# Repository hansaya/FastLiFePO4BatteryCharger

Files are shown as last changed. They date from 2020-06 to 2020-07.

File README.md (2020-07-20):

Fast battery charger designed to work with LifePo4 batteries using bq24630.

Features
* Selectable battery configuration. Up to 7S.
* Charge management based on temperature. Covers cold and warm conditions.
* Automatic system output selection based on power input conditions.
* No back feeding the input.
* High charging current up to 10A.
* Adjustable max input current limit.
* Adjustable max output current.
* Adjustable charge termination current.
* External enable pin can be used to turn on the charger. This is useful when you want to use the car ignition switch to trigger the charging.

More info at https://www.ti.com/lit/ds/symlink/bq24630.pdf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

# Disclaimer

**I’m not responsible for any life or property damage. Do your own research and use my design at your own risk. Lithium batteries can be dangerous.**

# My use case

I currently own an dash cam that can record time lapses while car is parked. This is a great feature and find it to be useful. However this requires the camera to be connected to constant power source. Plugging a camera into car battery permanently will get you a empty battery eventually. Specially if you don’t start the car every day. My solution to this problem is to have an secondary battery pack that powers the camera. 

My requirements:
1) Fast charge the battery within 20min or so. ie within in my daily commute.
2) Battery pack needs to handle the high heat and subzero conditions safely.
3) Runs system like a UPS. No interruptions to the output.
4) High charge cycles so that system would last for a long time.

# Design consideration.
1)	Picked bq24630 ic by TI as the solution to this problem. Which covers all my asks.
2)	Picked LifePo4 battery pack for temperature and charge cycle resiliency. Plus less like to detonate inside the car.
3)	2-layes 1oz board to make PCB house manufacturing cost down.
4)	Went with 3S configuration to keep the battery voltage bellow the input voltage. Bq24630 only a buck converter so it needs some head room.
5)	Keep the battery management work out of this design for simplicity.

# Board files

You can use the zip file within cam/ folder to get the board made by a PCB house. Board can be made with 2-layer and 1oz copper. If you have the money for higher copper thickness go for it but not required. 

## Assembling the board

* Do SMT soldering for all parts except for connectors and the fuse holders. 
* Trim pots are not required but recommended if you want to tweak the current settings. If you do select the trim ports, **DO NOT INSTALL R4, R5, R16, R17, R18 and R19.** R4 and R5 is used to set the charging current, R17 and R17 for termination current and finally R18 and R19 is for adapter current limit. Default values set on schematic designed for 4A adapter current limit, 3A charging current limit and 0.3A termination current.
* NTC thermistor required to let the charger operate at full current. 1.9v at the NTC positive legs could trigger into normal operation mode for testing.
* Add solder to no mask section to increase the current capabilities. This is how I got away with 1oz copper.
* R13 and R14 can be used to set the output voltage. Use 1.8(1+R13/R14) to set the voltage. My schematic sets this at 10.8V (LifePo4 3S).
* C11 can be used to set the safety timer. Checkout the datasheet for more information.
* P-CH mosfets I picked are only designed for 20v so do not exceed 20v input voltage.
* LED outputs are not required but handy to have.
* EN solder jumper can be used to permanently turn on the input.
* TB1 cab be used to reroute the charge enable pin to the external connector. Use a sharp knife to cut the trace between default charge enable tab.
* Q7 is optional if the charger needs to be enabled by default. Use a jumper to bridge the mosfet pads.

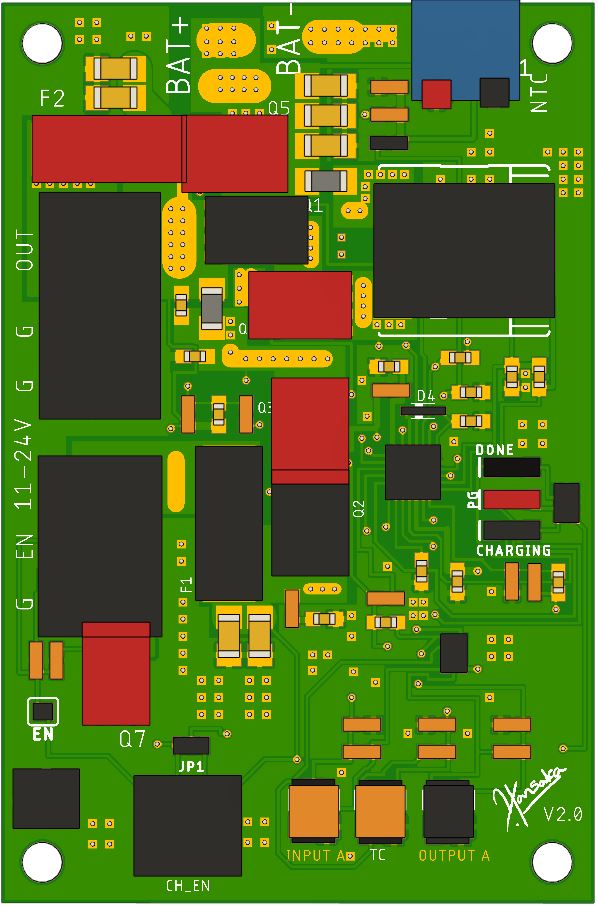
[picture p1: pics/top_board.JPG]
Top Board look

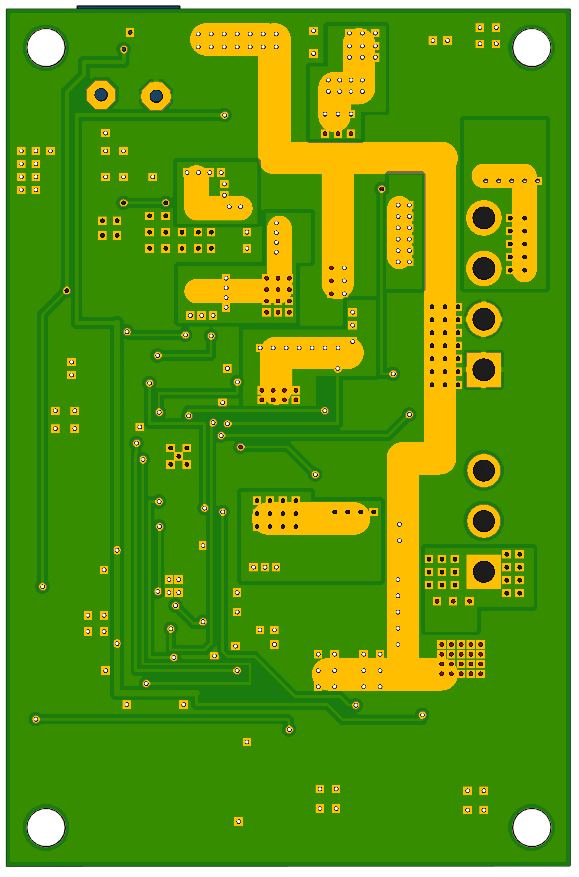
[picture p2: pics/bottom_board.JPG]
Bottom board look


# Other considerations

* Install an external battery protection system between the battery and the charger. 
* Even though charger can do 10A, inductor seems to get bit toasty at that level of current. I find 6A to be a happy medium.

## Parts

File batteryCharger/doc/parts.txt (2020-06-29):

bq24630 Standalone Synchronous Switched-Mode Lithium Phosphate Battery Charger
https://www.ti.com/lit/ds/symlink/bq24630.pdf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
https://www.digikey.com/product-detail/en/vishay-siliconix/SIR401DP-T1-GE3/SIR401DP-T1-GE3CT-ND/6595354

current sensing https://www.digikey.com/product-detail/en/panasonic-electronic-components/ERJ-8CWJR010V/P0-01BWCT-ND/4927054
Capacitors 10uF https://www.digikey.com/product-detail/en/samsung-electro-mechanics/CL31A106MAHNNNE/1276-1181-1-ND/3889267

connector https://www.digikey.com/product-detail/en/jst-sales-america-inc/VHR-4M/455-3990-ND/9924201
connector https://www.digikey.com/product-detail/en/jst-sales-america-inc/B4P-VH-FB-B-LF-SN/455-3979-ND/7230471
connector https://www.digikey.com/product-detail/en/jst-sales-america-inc/SVH-41T-P1-1/455-1319-1-ND/608888

resistor 82K https://www.digikey.com/product-detail/en/bourns-inc/CAY16-823J4LF/CAY16-823J4LFCT-ND/3767645

thermistor https://www.digikey.com/products/en/sensors-transducers/temperature-sensors-ntc-thermistors/508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

opto https://www.digikey.com/product-detail/en/broadcom-limited/HCPL-181-00BE/516-1787-1-ND/1966493

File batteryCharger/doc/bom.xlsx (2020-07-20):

Part name | Part number | price | location
Charger IC | BQ24630 | 4.6 | https://www.digikey.com/product-detail/en/BQ24630RGER/296-41208-1-ND/5222664/?itemSeq=331097642
opto 5.8UH | LTV-816S | 0.43 | https://www.digikey.com/product-detail/en/broadcom-limited/HCPL-181-00BE/516-1787-1-ND/1966493
inductor | CEP125 | 2.73 | https://www.digikey.com/product-detail/en/sumida-america-components-inc/CEP125NP-5R6MC-H/308-2325-1-ND/4356394
Thermister 10K | ACM011 | 3.3 | https://www.digikey.com/short/z9ht3w
resistor array 82K | CAY16-823J4LF | 0.1 | https://www.digikey.com/product-detail/en/bourns-inc/CAY16-823J4LF/CAY16-823J4LFCT-ND/3767645
Female 4p Connector | VHR-4M | 0.18 | https://www.digikey.com/product-detail/en/jst-sales-america-inc/VHR-4M/455-3990-ND/9924201
Male 4p Connector | B4P-VH-FB-B(LF)(SN) | 0.39 | https://www.digikey.com/product-detail/en/jst-sales-america-inc/B4P-VH-FB-B-LF-SN/455-3979-ND/7230471
Female header pins | SVH-41T-P1.1 | 0.12 | https://www.digikey.com/product-detail/en/jst-sales-america-inc/SVH-41T-P1-1/455-1319-1-ND/608888
Female 3p Connector | VHR-3N | 0.14 | https://www.digikey.com/product-detail/en/jst-sales-america-inc/VHR-3N/455-1184-ND/608625
Male 3p Connector | B3P-VH-FB-B(LF)(SN) | 0.36 | https://www.digikey.com/product-detail/en/jst-sales-america-inc/B3P-VH-FB-B-LF-SN/455-3978-ND/2741627
Current sensor 0.01 | ERJ-8CWJR010V | 0.52 | https://www.digikey.com/product-detail/en/panasonic-electronic-components/ERJ-8CWJR010V/P0-01BWCT-ND/4927054
Capacitor 10uf | CL31A106MAHNNNE | 0.2 | https://www.digikey.com/product-detail/en/samsung-electro-mechanics/CL31A106MAHNNNE/1276-1181-1-ND/3889267
P-Channel mos | SIR401DP-T1-GE3 | 0.92 | https://www.digikey.com/product-detail/en/vishay-siliconix/SIR401DP-T1-GE3/SIR401DP-T1-GE3CT-ND/6595354
N-Channel mos | SIRA18ADP-T1-GE3 | 0.41 | https://www.digikey.com/product-detail/en/vishay-siliconix/SIRA18ADP-T1-GE3/SIRA18ADP-T1-GE3CT-ND/8556380
Trim pot 50K | TC33X-2-503E | 0.28 | https://www.digikey.com/product-detail/en/bourns-inc/TC33X-2-503E/TC33X-503ECT-ND/612915
resistor array 10K | CAY16-103J4LF | 0.1 | https://www.digikey.com/product-detail/en/bourns-inc/CAY16-103J4LF/CAY16-103J4LFCT-ND/3437832
JST connector | S2B-PH-SM4-TB | 0.58 | https://www.digikey.com/product-detail/en/jst-sales-america-inc/S2B-PH-SM4-TB-LF-SN/455-1749-1-ND/926846
1808 Fuse holder | 1808 Fuse holder | 0.2 | https://www.aliexpress.com/item/4000013163243.html?spm=a2g0s.9042311.0.0.2eca4c4dg8351D
1808 Fuse | 1808 Fuse | 0.27 | https://www.aliexpress.com/item/4000063485981.html
Total |  | 15.83

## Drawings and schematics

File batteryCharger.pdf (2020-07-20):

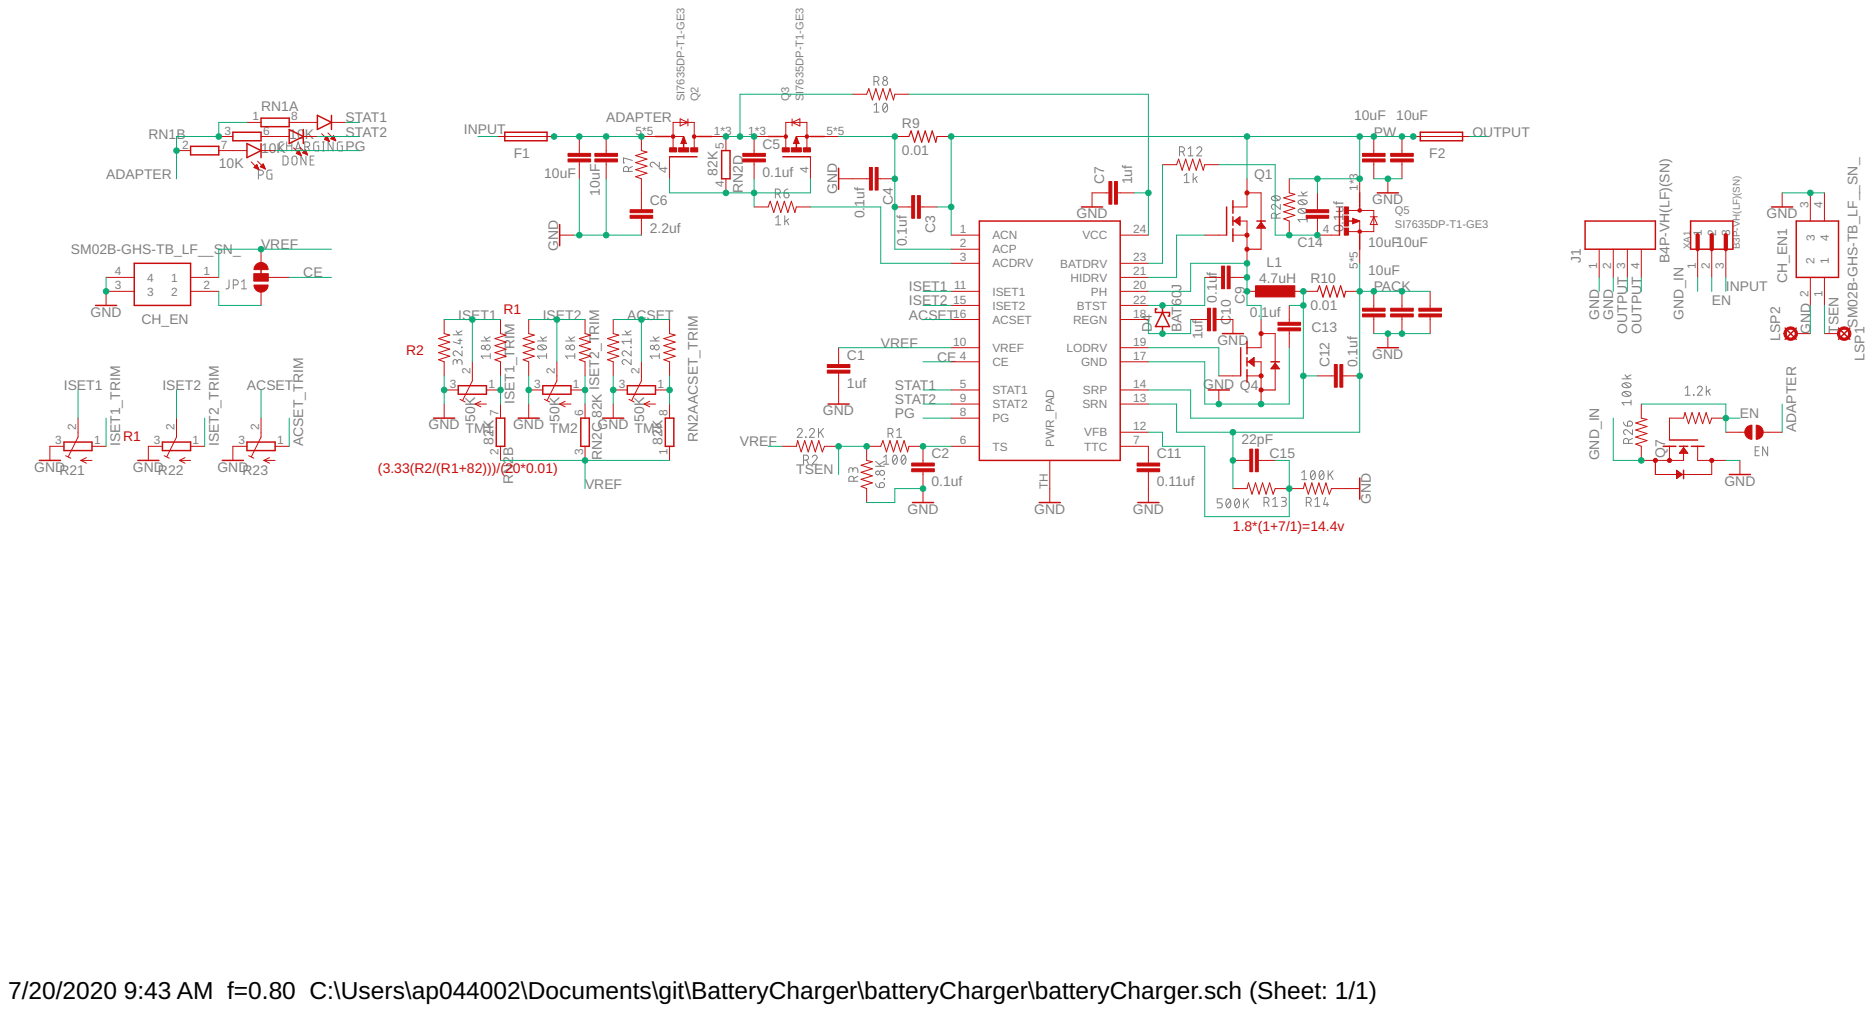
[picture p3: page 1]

7/20/2020 9:43 AM f=0.80 C:\Users\ap044002\Documents\git\BatteryCharger\batteryCharger\batteryCharger.sch (Sheet: 1/1)

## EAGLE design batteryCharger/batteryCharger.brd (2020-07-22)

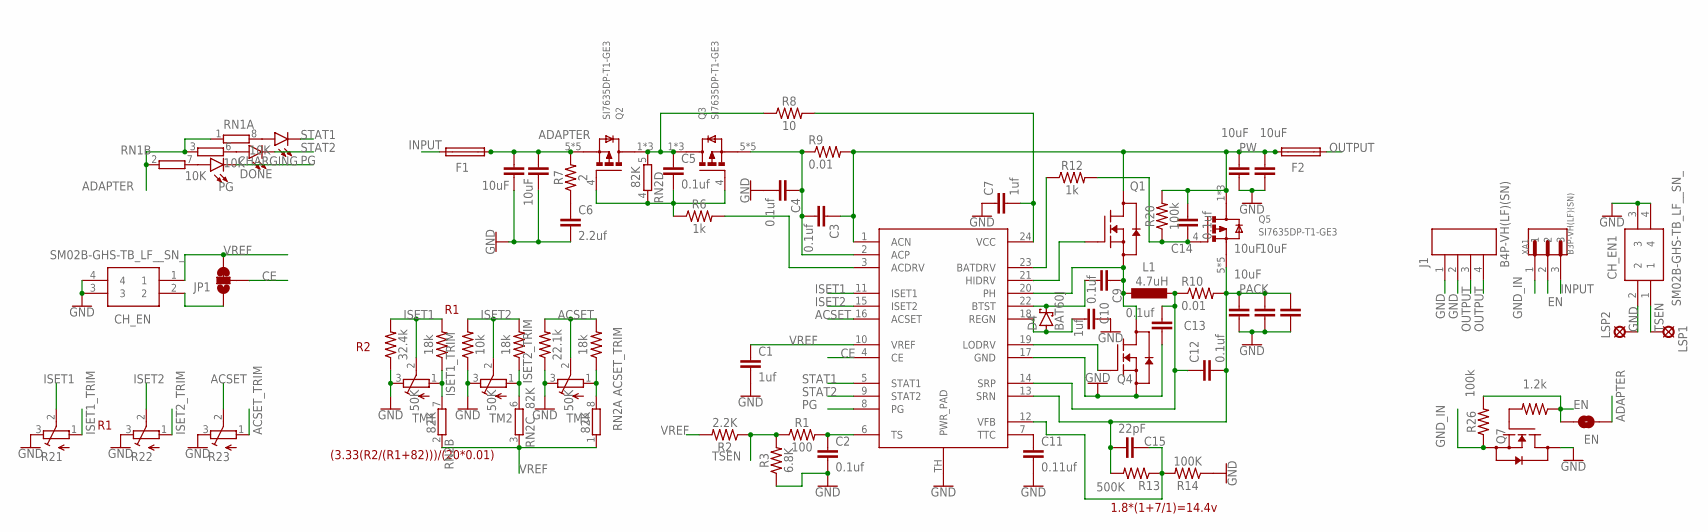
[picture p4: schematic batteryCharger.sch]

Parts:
C1, C7, C10: 1uf; C0603
C2, C3, C4, C5, C9, C12, C13, C14: 0.1uf; C0603
C6: 2.2uf; C0603
C11: 0.11uf; C0603
C15: 22pF; C0603
C16, C17, C18, C19, C20, C21, C22: 10uF; C1206
CHARGING: LED1206; LED-1206
CH_EN, CH_EN1: SM02B-GHS-TB_LF__SN_; SM02BGHSTBLFSN
D4: BAT60J; SOD323_ST
DONE: LED1206; LED-1206
EN: JUMPER-SMT_2_NO_SILK; SMT-JUMPER_2_NO_SILK
F1, F2: SMD-MICRO-FUSE-BLOCK; OMNIBLOK
J1: B4P-VH(LF)(SN); JST_B4P-VH(LF)(SN)
JP1: JUMPER-SMT_3_1-NC_TRACE_NO-SILK; SMT-JUMPER_3_1-NC_TRACE_NO-SILK
L1: 4.7uH; CEP125
LSP1, LSP2: LSP10
PG: LED1206; LED-1206
Q1, Q4, Q7: SIR414DP-T1-GE3; TRANS_SQJ461EP-T1-GE3
Q2, Q3, Q5: SI7635DP-T1-GE3; TRANS_SI7635DP-T1-GE3
R1: 100; 0603
R2: 2.2K; 0603
R3: 6.8K; 0603
R4: 32.4k; 0603
R5, R17, R19: 18k; 0603
R6, R12: 1k; 0603
R7: 2; 0603
R8: 10; 0603
R9, R10: 0.01; R1206
R13: 500K; 0603
R14: 100K; 0603
R16: 10k; 0603
R18: 22.1k; 0603
R20, R26: 100k; 0603
R21, R22, R23: TRIM_EU-3223W; 3223W
R25: 1.2k; 0603
RN1: 10K; 0603-ARC
RN2: 82K; CAY16
TM1, TM2, TM3: 50K; TC33X
U$1: BQ24630VQFN24; HVQFN24
XA1: B3P-VH(LF)(SN); JST_B3P-VH(LF)(SN)

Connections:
ACSET: R18.2, R19.2, R23.2 (S), TM3.2 (S), U$1.16 (ACSET)
ACSET_TRIM: R19.1, R23.1 (A), RN2.8 (2), TM3.1 (A)
ADAPTER: C21.1, C22.1, EN.1, F1.P$1 (1), Q2.5 (D), Q2.6 (D), Q2.7 (D), Q2.8 (D), Q2.9 (D), R7.2, RN1.1, RN1.2 (1), RN1.3 (1)
CE: JP1.2, U$1.4 (CE)
EN: EN.2, R25.1, R26.2, XA1.2
GND: C1.2, C2.2, C4.2, C6.2, C7.1, C10.2, C11.2, C13.1, C16.2, C17.2, C18.2, C19.2, C20.2, C21.2, C22.2, CH_EN.3, CH_EN.4, CH_EN1.2, CH_EN1.3, CH_EN1.4, J1.1, J1.2, LSP2.MP, Q4.1 (S), Q4.2 (S), Q4.3 (S), Q7.5 (D), Q7.6 (D), Q7.7 (D), Q7.8 (D), Q7.9 (D), R3.1, R4.1, R14.1, R16.1, R18.1, R21.3 (E), R22.3 (E), R23.3 (E), TM1.3 (E), TM2.3 (E), TM3.3 (E), U$1.17 (GND), U$1.TH (PWR_PAD)
GND_IN: Q7.1 (S), Q7.2 (S), Q7.3 (S), R26.1, XA1.1
INPUT: F1.P$2 (2), XA1.3
ISET1: R4.2, R5.2, R21.2 (S), TM1.2 (S), U$1.11 (ISET1)
ISET1_TRIM: R5.1, R21.1 (A), RN2.7 (2), TM1.1 (A)
ISET2: R16.2, R17.2, R22.2 (S), TM2.2 (S), U$1.15 (ISET2)
ISET2_TRIM: R17.1, R22.1 (A), RN2.6 (2), TM2.1 (A)
unnamed: C2.1, R1.2, U$1.6 (TS)
unnamed: CHARGING.A, RN1.8 (2)
unnamed: CH_EN.2, JP1.1
unnamed: Q7.4 (G), R25.2
unnamed: DONE.A, RN1.6 (2)
unnamed: PG.A, RN1.7 (2)
unnamed: C9.2, D4.C, U$1.22 (BTST)
unnamed: C5.1, Q2.1 (S), Q2.2 (S), Q2.3 (S), Q3.1 (S), Q3.2 (S), Q3.3 (S), R8.1, RN2.5 (2)
unnamed: R6.2, U$1.3 (ACDRV)
unnamed: C3.2, C4.1, Q3.5 (D), Q3.6 (D), Q3.7 (D), Q3.8 (D), Q3.9 (D), R9.1, U$1.2 (ACP)
unnamed: C15.1, R13.1, R14.2, U$1.12 (VFB)
unnamed: C7.2, R8.2, U$1.24 (VCC)
unnamed: Q1.4 (G), U$1.21 (HIDRV)
unnamed: C6.1, R7.1
unnamed: C12.1, C13.2, L1.2, R10.1, U$1.14 (SRP)
unnamed: C10.1, D4.A, U$1.18 (REGN)
unnamed: Q4.4 (G), U$1.19 (LODRV)
unnamed: C9.1, L1.1, Q1.1 (S), Q1.2 (S), Q1.3 (S), Q4.5 (D), Q4.6 (D), Q4.7 (D), Q4.8 (D), Q4.9 (D), U$1.20 (PH)
unnamed: C11.1, U$1.7 (TTC)
unnamed: C14.1, Q5.4 (G), R12.2, R20.1
unnamed: C5.2, Q2.4 (G), Q3.4 (G), R6.1, RN2.4 (1)
unnamed: R12.1, U$1.23 (BATDRV)
OUTPUT: F2.P$1 (1), J1.3, J1.4
PACK: C12.2, C15.2, C16.1, C17.1, C18.1, Q5.5 (D), Q5.6 (D), Q5.7 (D), Q5.8 (D), Q5.9 (D), R10.2, R13.2, U$1.13 (SRN)
PG: PG.C, U$1.8 (PG)
PW: C3.1, C14.2, C19.1, C20.1, F2.P$2 (2), Q1.5 (D), Q1.6 (D), Q1.7 (D), Q1.8 (D), Q1.9 (D), Q5.1 (S), Q5.2 (S), Q5.3 (S), R9.2, R20.2, U$1.1 (ACN)
STAT1: CHARGING.C, U$1.5 (STAT1)
STAT2: DONE.C, U$1.9 (STAT2)
TSEN: CH_EN1.1, LSP1.MP, R1.1, R2.1, R3.2
VREF: C1.1, CH_EN.1, JP1.3, R2.2, RN2.1, RN2.2 (1), RN2.3 (1), U$1.10 (VREF)

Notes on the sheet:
1.8*(1+7/1)=14.4v
(3.33(R2/(R1+82)))/(20*0.01)

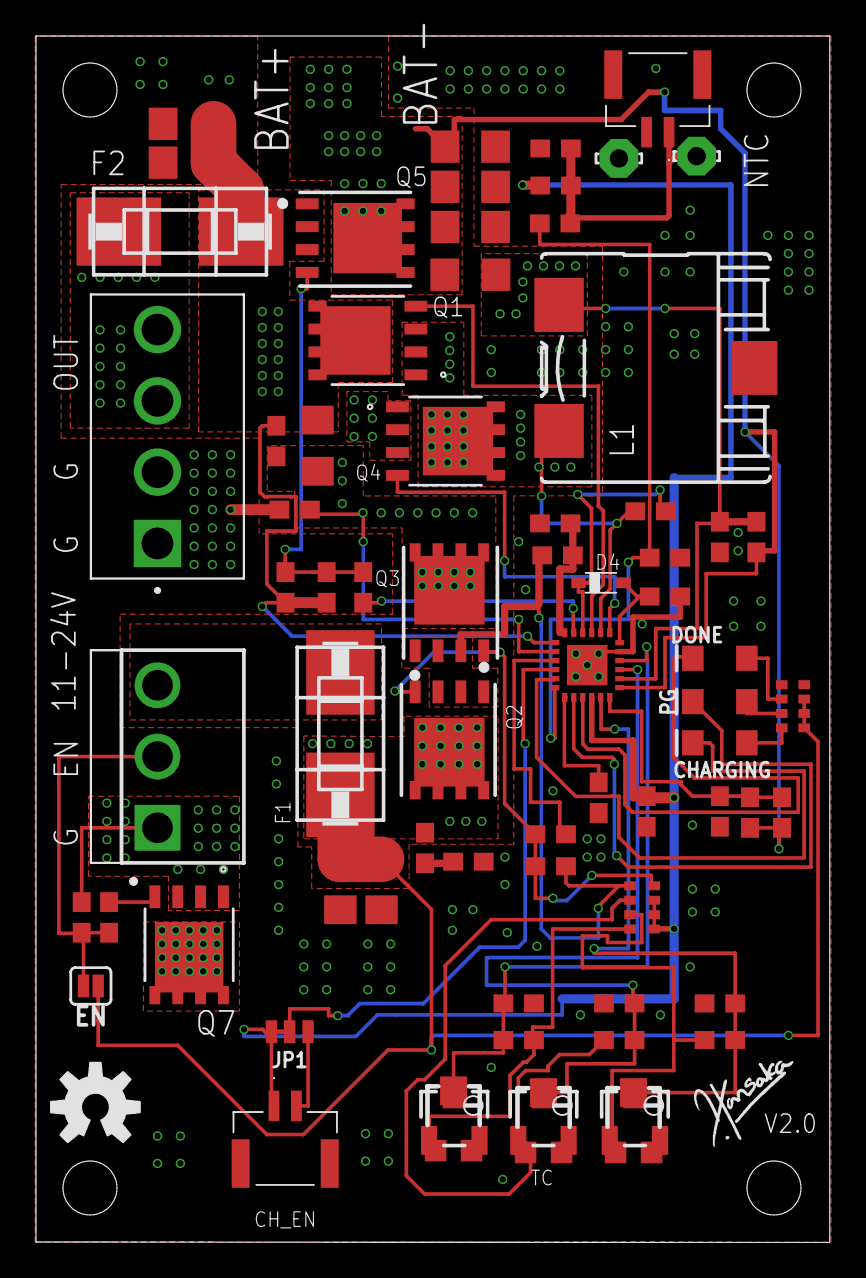
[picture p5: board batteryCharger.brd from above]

Board: 2 copper layers, 44.1 x 67.0 mm, 73 parts (0 on the bottom side), 42 nets.

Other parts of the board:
U$2: SIGNATURE
U$3: OSHW-LOGO-M

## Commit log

2020-07-01 final board file
    [batteryCharger.brd, batteryCharger.sch]
2020-07-11 v2 with bug fixses
    [batteryCharger.brd, batteryCharger.sch, bom.xlsx]
2020-07-13 Bug fixses
    [batteryCharger.brd, batteryCharger.sch]
2020-07-13 Add eagle libs for charger and connectors
2020-07-20 Change the enable pin design
    [batteryCharger.brd, batteryCharger.sch]
2020-07-20 Clean up
    [batteryCharger.brd, bom.xlsx]

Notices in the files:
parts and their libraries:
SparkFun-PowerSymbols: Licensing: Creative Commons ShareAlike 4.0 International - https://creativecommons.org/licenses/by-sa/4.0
